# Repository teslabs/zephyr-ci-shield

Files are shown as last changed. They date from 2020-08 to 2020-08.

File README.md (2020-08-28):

# Zephyr CI Test Shield

This repository contains the board design files for the Zephyr CI Test Shield.
This board is a clone of the ARM mbed CI test shield.

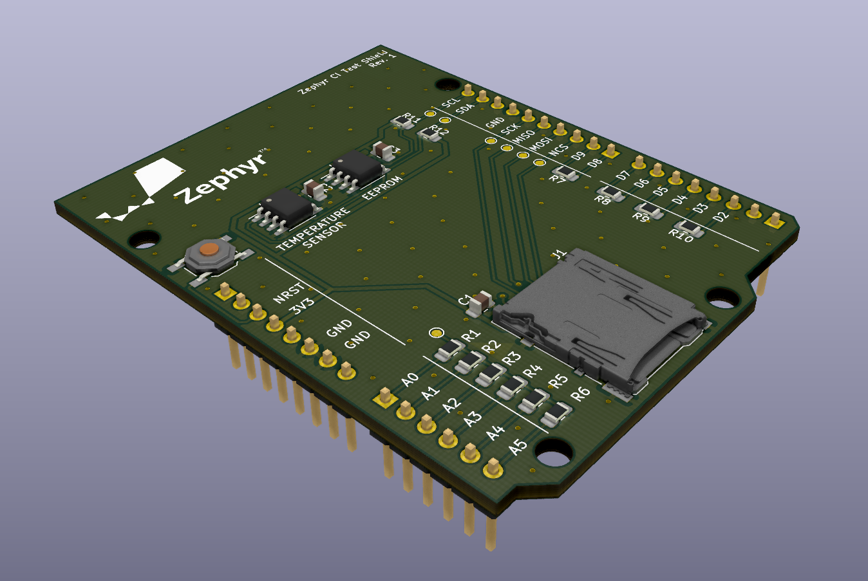
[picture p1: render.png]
Board render


## What is included

* KiCad (5.x) schematic and board files
* Part numbers for JLCPCB assembly (only SMD parts)
* Part numbers from Mouser
* For every revision:
  - Schematic PDF
  - GERBER files
  - BOM and assembly files for JLCPCB
  - Interactive HTML BOM

## Features

* Arduino R3 shield format
* microSD card slot to test SPI
* Resistor star network to test ADC
* EEPROM and temperature sensor to test I2C, EEPROM drivers and sensor drivers
* Loopback pins to test digital inputs, outputs, interrupts, PWM...
* Multiple accessible test points

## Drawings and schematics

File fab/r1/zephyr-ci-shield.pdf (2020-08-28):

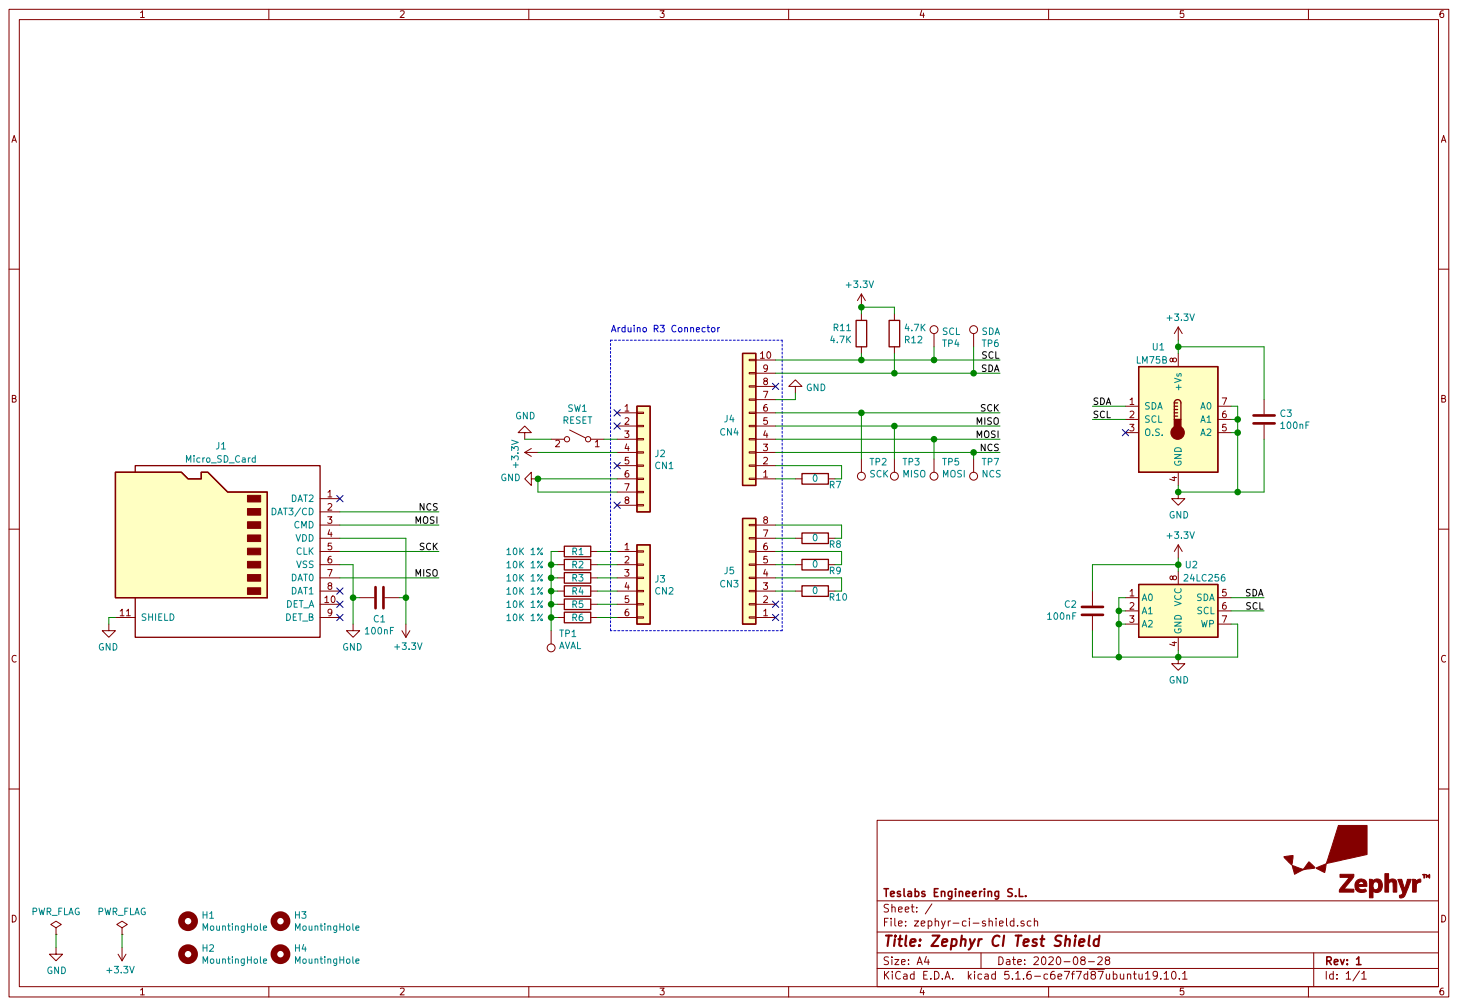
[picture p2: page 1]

4 SDA 5 SCL 6 WP 7 VCC

Id: 1/1 Title: Zephyr CI Test Shield

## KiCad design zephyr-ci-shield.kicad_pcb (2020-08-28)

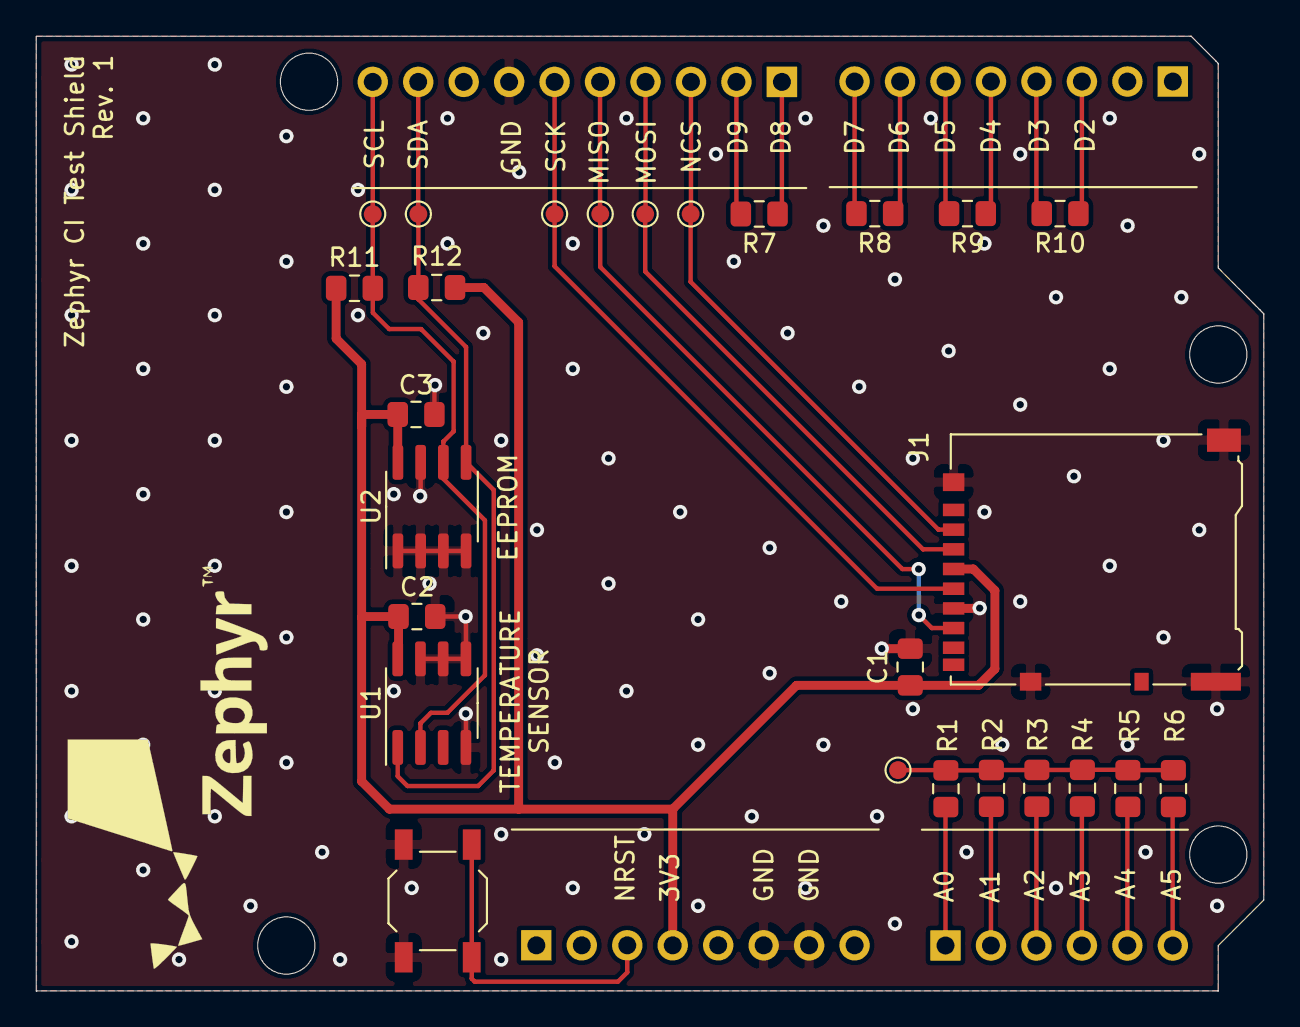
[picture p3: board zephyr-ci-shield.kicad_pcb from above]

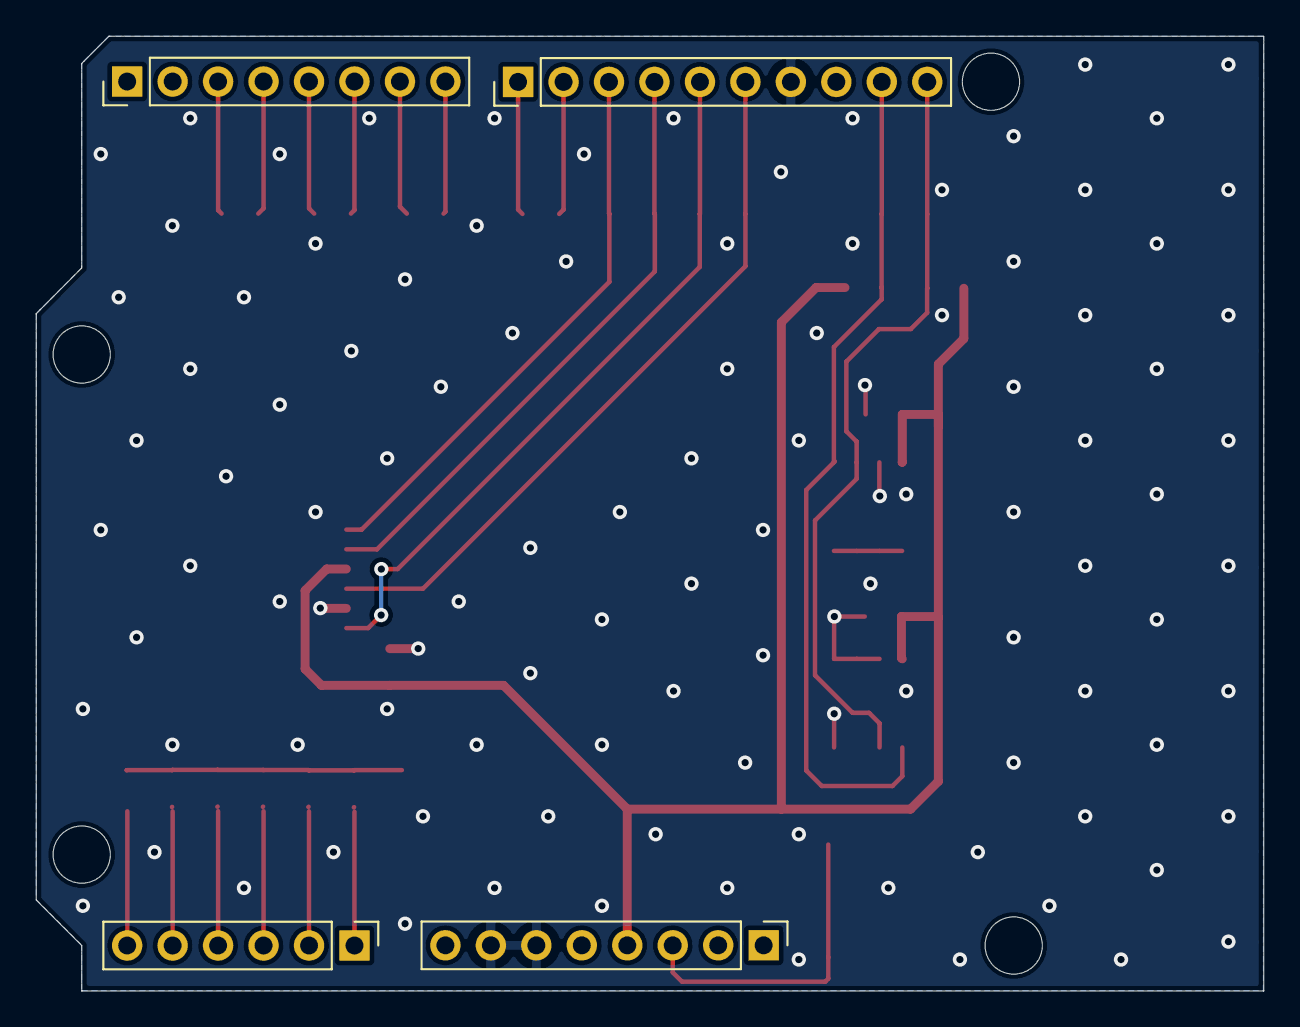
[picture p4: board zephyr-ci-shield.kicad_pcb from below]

Board: 2 copper layers, 68.6 x 53.3 mm, 34 parts (4 on the bottom side), 24 nets.

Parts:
C1, C2, C3: 100nF; C_0805_2012Metric_Pad1.15x1.40mm_HandSolder
H1, H2, H3, H4: MountingHole; MountingHole_3.2mm
J1: Micro_SD_Card; microSD_HC_Hirose_DM3AT-SF-PEJM5
J2: CN1; PinHeader_1x08_P2.54mm_Vertical
J3: CN2; PinHeader_1x06_P2.54mm_Vertical
J4: CN4; PinHeader_1x10_P2.54mm_Vertical
J5: CN3; PinHeader_1x08_P2.54mm_Vertical
R1, R2, R3, R4, R5, R6: 10K; R_0805_2012Metric_Pad1.15x1.40mm_HandSolder
R7, R8, R9, R10: 0; R_0805_2012Metric_Pad1.15x1.40mm_HandSolder
R11, R12: 4.7K; R_0805_2012Metric_Pad1.15x1.40mm_HandSolder
SW1: RESET; SW_SPST_TL3342
TP1: AVAL; TestPoint_Pad_D1.0mm
TP2: SCK; TestPoint_Pad_D1.0mm
TP3: MISO; TestPoint_Pad_D1.0mm
TP4: SCL; TestPoint_Pad_D1.0mm
TP5: MOSI; TestPoint_Pad_D1.0mm
TP6: SDA; TestPoint_Pad_D1.0mm
TP7: NCS; TestPoint_Pad_D1.0mm
U1: LM75B; SOIC-8_3.9x4.9mm_P1.27mm
U2: 24LC256; SOIC-8_3.9x4.9mm_P1.27mm

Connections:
+3V3: C1.2, C2.2, C3.1, J1.4, J2.4, R11.1, R12.1, U1.8, U2.8
/MISO: J1.7, J4.5, TP3.1
/MOSI: J1.3, J4.4, TP5.1
/NCS: J1.2, J4.3, TP7.1
/SCK: J1.5, J4.6, TP2.1
/SCL: J4.10, R11.2, TP4.1, U1.2, U2.6
/SDA: J4.9, R12.2, TP6.1, U1.1, U2.5
GND: C1.1, C2.1, C3.2, J1.6, J1.11, J2.6, J2.7, J4.7, SW1.2, U1.4, U1.5, U1.6, U1.7, U2.1, U2.2, U2.3, U2.4, U2.7
unnamed: J2.3, SW1.1
unnamed: J3.1, R1.2
unnamed: J3.2, R2.2
unnamed: J3.3, R3.2
unnamed: J3.4, R4.2
unnamed: J3.5, R5.2
unnamed: J3.6, R6.2
unnamed: J4.1, R7.1
unnamed: J4.2, R7.2
unnamed: J5.3, R10.1
unnamed: J5.4, R10.2
unnamed: J5.5, R9.1
unnamed: J5.6, R9.2
unnamed: J5.7, R8.1
unnamed: J5.8, R8.2
unnamed: R1.1, R2.1, R3.1, R4.1, R5.1, R6.1, TP1.1
